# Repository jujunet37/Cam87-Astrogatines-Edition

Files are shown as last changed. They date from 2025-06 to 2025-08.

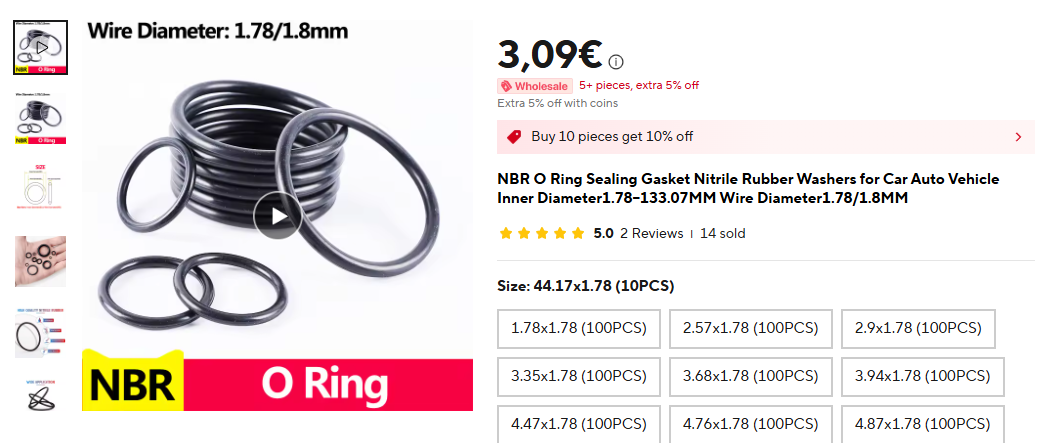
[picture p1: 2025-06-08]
Parts/captures/Capture d'écran 2025-06-08 154612.png

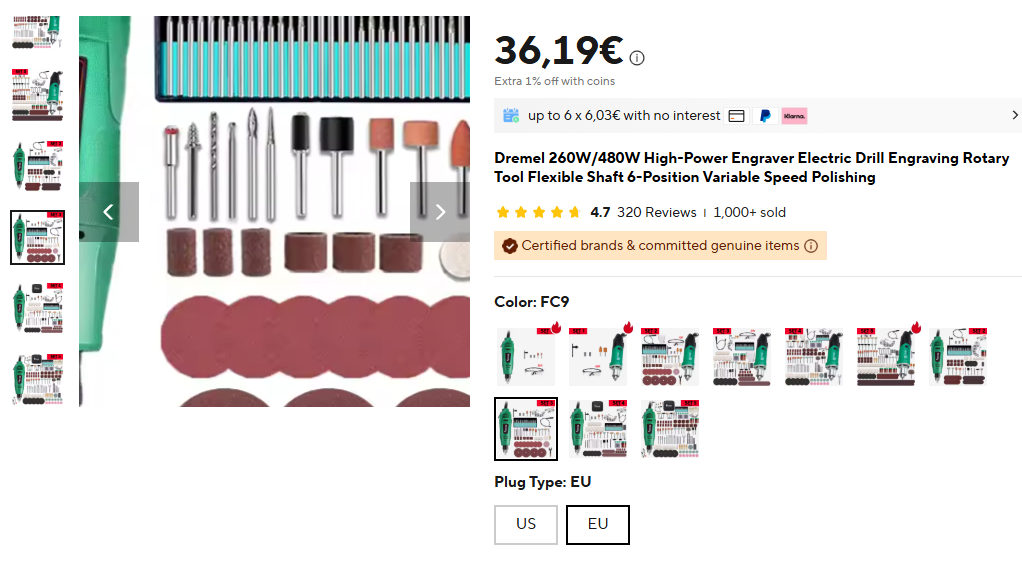
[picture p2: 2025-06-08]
Parts/Other stuff/Capture d'écran 2025-06-08 154455.png

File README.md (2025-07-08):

# Cam87-Astrogatines-Edition

## This repository contains all files needed to build the astronomy Cam87 color camera with a APSC CCD sensor. The resolution of this camera is 6M pixels (3000x2000). Original wiring diagram was made by grim from Astroclub.kiev.ua. Budget for this camera is about 280€ / 320$

## Here are the implementation I made :

- Keep gastight Hammond aluminium enclosure for best low humidity performance and interference shield.
- Power board with all high frequency components are outside the metal box.
- New PCB checked with 4 layers. All logic components on the back side of the sensor side, 3 layers of tracks and a inner full copper plane for best grounding.
- New tiny Mosfet AO4410 that can go up to 18A, tracks are sized for 3.5A max, no more heating mosfet.
- New PID controlled by an ESP32 including a webserver and a new webapp ! Access to sensor and case temperature, box humidity and a temperature graph with your phone or a computer (wifi connexion).
- New design with a aluminium cold finger pressed against the metal box with a 3D printed part. No machining anymore, the .step file is inclued to let it jlccnc do the job !
- Stl files provided for power board holder and enclosure with ESP32 location. Black sensor mask, Cold finger insulator. I provided also a shim to help drilling the lid at the right place.

## Folders :

First folders are numbered for each installation step (Look at the tutorial for each step) : 

- 1 - Drivers FT2232 : Drivers for Windows for the FT2232. I provided 2 drivers, you can check for updates on FTDI website, type FT2232HL and install lastest drivers. WARNING : Since several years FTDI brick non genuine chips. If you purchased your chip on an official reseller, you can update to last driver. If your chip comes from Aliexpress or EBay, be careful about that, if you have any doubt, install the 2.08 provided driver.

- 2 - Flash FT2232 : This is the firmware and the programming utility for flashing the FT2232 chip

- 3a - Viewer : This is the standalone viewer to use with this camera, developped by grim.

- 3b - Flash STM32 : This is the STM32 flash file and the ST-LINK utility for flashing.

- ESP32 PID : In this folder you can found the .ino file for the ESP32 PID and the files to upload on the board for the webserver.

- Gerbers : gerbers files to make the 4 layers PCB (choose 1oz for each layer for cam pcb and 1oz external 0.5oz inner for power board)

- Old ASCOM Platform : This is the ASCOM platform version 6.2 that works with this camera, I  haven't tried newer versions.

- Parts : Here you have the list of components and screen captures to see what parts you need. Also some diagrams.

- STL and STEP Files : This is the stl files for 3D printing and the step file for aluminium CNC machining.

- Wiring diagram : The corrected wiring diagram including the new ESP32 PID and the new cooling diagram.

	- SSID for PID : Cam87 Cooling
	- Password : Value of the speed of the photons that reach your nice camera, in m/s ;-)
	- IP for access : 192.168.4.1

YOUTUBE TUTORIALS !

English : https://www.youtube.com/watch?v=FVaMk6Fg4kI
French : https://www.youtube.com/watch?v=qr7sxIyBGCc

FTDI : https://ftdichip.com/
Astroccd : http://astroccd.org/
Ukrainian Astropolis topic : https://www.astroclub.kiev.ua/forum/index.php?PHPSESSID=su8vh9h1n0l7lrnate4rmb50v5&topic=28929.0

## UPDATE 08/07/2025 :

3D Parts corrected :
- Sensor mask : removed weird cut
- Powerboard Holder : corrected to let the board fit correctly
- Powerboard holder lid : Back corrected for PCB and ESP32 chamber resized.

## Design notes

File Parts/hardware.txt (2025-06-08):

Filtre UV/IR cut 2 inches : SVBONY 2" Filter, UV/IR Cut : 23.98€
Peltier TEC2-19003 30*30*6.0 : 11.09€
Capteur : CCD Sensor for Nikon D70 Image Replacement Repair Part New : 18.32€
ESP32 D1 Mini ESP32 WIFI Bluetooth Development Board CH9102 With ESP-WROOM-32 Module Type-C USB Interface For Arduino : 6.55€

Electronics: €60.85
Hammond Case: €21.17
PCB 1oz/0.5oz Power Supply, 1oz/1oz Logic: €36.25/5 = €7.25

Port Parts:

O-ring 44.17*1.78: €0.60
Silicone Disc 60mmx2mm: €3.18
15mm M48 Bushing: €18.30
M52/M48 Bushing + Cap: €9
M48/M42 Bushing: €3.26

Heat Sink: €18.59
Springs: see details

PU Glue: €6.09
Cold Finger Seals: €1.10
Machined Cold Finger: €46
3D Printing: €14.68
Fan : use again

Screws: €6.54

Details:
M2.5 Nuts: 8: €0.21
M2.5 Flat Head Bolts, 6mm: 2: €0.10
M2.5 Round Head Bolts, 8mm: 2: €0.10
M2.5 Flat Head Bolts, 10mm: 4: €0.16
M2.5 Flat Head Bolts, 16mm: 2: €0.10

M3 Nuts: 10: €0.21
M3 Flat Head Bolts, 6mm: 11: €0.46
M3 Flat Head Bolts, 10mm: 4: €0.20
M3 Washers, 8mm, 0.8mm thick: 8: €0.20
M3 Spacer, 4mm: 11: €1.51
M3 Spacer, 15mm: 4: €0.54

M4 Nuts: 8: €0.48
M4 Flat Head Bolts: 22mm: 4: €0.47
M4 Flat Head Bolts: 40mm: 4: €0.66

Springs: 6mm diameter, 0.6mm wire, 15mm length: 4: €0.54
Springs: 5mm diameter, 0.4mm wire, 5mm length: 4: €0.60

Total: €276

Optional:

M48 TILT Ring: €28.31
M48 Male -> EOS Adapter: €28.39

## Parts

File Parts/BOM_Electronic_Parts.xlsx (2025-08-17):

Resistors
Serigraphy | Size | Value | Number | Reference | Supplier | Shop | Comments
 |  |  |  |  | MULTICOMP PRO | FARNELL
R6S,R11L | R0603 | 100kΩ | 2 | WR06X1003FTL | MULTICOMP PRO | FARNELL
R4S | R0603 | 100Ω | 1 | MCWR06X1000FTL | MULTICOMP PRO | FARNELL
R10L,R14L,R15L,R6L,R11 | R0603 | 10kΩ | 5 | WR06X1002FTLJ | MULTICOMP PRO | FARNELL
R7 | R0603 | 10kΩ | 1 | WR06X1002FTLJ | MULTICOMP PRO | FARNELL
R7L | R0603 | 12kΩ | 1 | WF06P1202FTL | MULTICOMP PRO | FARNELL
R1 | R0603 | 13kΩ | 1 | MCWR06X1302FTL | MULTICOMP PRO | FARNELL
R5 | R0603 | 180Ω | 1 | MCWR06X1800FTL | MULTICOMP PRO | FARNELL
R8L | R0603 | 1kΩ | 1 | WR06X1001FTL | PANASONIC | FARNELL
R7S | R0805 | 1MΩ | 1 | ERJU06F1004V | MULTICOMP PRO | FARNELL
R9L | R0603 | 2.2kΩ | 1 | MR06X2201FTLV | MULTICOMP PRO | FARNELL
R2 | R0603 | 2.4kΩ | 1 | MCWR06X2401FTL | MULTICOMP PRO | FARNELL
R8 | R1206 | 221Ω | 1 | RC1206FR-07221RL | MULTICOMP PRO | FARNELL
R17 | R0603 | 22kΩ | 1 | MCWR06X2202FTL | MULTICOMP PRO | FARNELL
R8S | R0603 | 22Ω | 1 | WR06X22R0FTL | MULTICOMP PRO | FARNELL
R9S | R0603 | 24kΩ | 1 | MCSR06X2402FTL | MULTICOMP PRO | FARNELL
R6 | R0603 | 2kΩ | 1 | MCWR06X2001FTL | VISHAY | FARNELL
R1S,R2S,R10S | R0603 | 3.01Ω | 3 | CRCW06033R01FKEA | MULTICOMP PRO | FARNELL
R9 | R0603 | 4.7kΩ | 1 | MCWR06X4701FTL | BOURNS | FARNELL
R3 | R0805 | 500mΩ | 1 | CRL0805-FW-R470ELF | YAGEO | FARNELL | (0.47 ohm)
R4 | R0805 | 220mΩ | 1 | - | Aliexpress | Aliexpress
R5S | R0603 | 510Ω | 1 | RC0603FR-07510RL | MULTICOMP PRO | FARNELL
R3S | R0603 | 750Ω | 1 | MCWR06X7500FTL |  | FARNELL
R10,R12 | R0603 | 0Ω | 0 | - | - | - | Testing (don't solder)
Capacitors :
C15,C1L,C34L,C22L,C28L,C30L,C31L,C27L,C8,C9L,C12,C12L,C15L,C21L,C26L,C29L,C33L, C1S,C3S | C0603 | 100nF | 19 | CC0603KRX7R9BB104 | YAGEO | FARNELL
C18S | C1206 | 100uF | 1 | GRM31CR60J107MEA8L | MURATA | FARNELL
C8L | CASE-B_3528 | 100uF | 1 | TAJB107K006RNJ | Kyocera AVX | FARNELL
C5S | C0603 | 10pF | 1 | CL10C100JB8NNNC | SAMSUNG ELECTRO-MECHANICS | FARNELL
C17L,C16L,C11L,C13,C16 | C0805 | 10uF | 5 | CL21A106KAYNNNE | SAMSUNG ELECTRO-MECHANICS | FARNELL
C17 | CAP-SMD_L7.3-W4.3-R-RD | 10uF | 1 | TAJD106K025RNJ | AVX | FARNELL
C2,C6,C25L,C36L,C6L,C37L,C7L,C14L,C9,C35L,C2S,C4S,C6S | C0603 | 1uF | 13 | EMK107B7105KA-T | TAIYO YUDEN | FARNELL
C3,C4 | C0603 | 330pF | 2 | GCM1885C1H331JA16D | MURATA | FARNELL
C1,C7,C10,C11 | CAP-SMD_L6.0-W3.2-R-RD | 220uF | 4 | TAJC227K010RNJ | Kyocera AVX | FARNELL | Low ESR
C5 | CAP-SMD_L7.3-W4.3 | 220uF | 1 | TPSE227K016R0050V | Kyocera AVX | FARNELL | Low ESR 0.05ohm vs 0.1 ohm liste LordZurp
C10L | C1206 | 47uF | 1 | CL31A476MPHNNNE | SAMSUNG ELECTRO-MECHANICS | FARNELL
C7S | CASE-D_7343 | 47uF | 1 | TAJD476K025RNJ | Kyocera AVX | FARNELL
C18 | CASE-D_7343 | 47uF | 1 | T491D476K025AT | KEMET | FARNELL
C14 | CAP-SMD_BD6.3-L6.6-W6.6-FD-A | 56uF | 1 | 25SVPF56M | PANASONIC | FARNELL
C23L,C24L | C0603 | 8.2pF | 2 | HH18N8R2B500 | MULTICOMP PRO | FARNELL
Inductors :
L1,L2 | IND-SMD_L12.5-W12.5 | 220uH | 2 | MSS1260T-224KLD | COILCRAFT | FARNELL
L1S | L0805 | 22uH | 1 | LQM21DN220M70L | MURATA | FARNELL
L3 | IND-SMD_L11.5-W10.0_SMMS1040 | 47uH | 1 | 47UH-1040 | - | Aliexpress
Diodes :
VD2S | SOD-123_L2.8-W1.8-LS3.7-RD | LMBR0530T1G | 1 | LMBR0530T1G | - | Aliexpress
D1,VD1,VD2 | SS34_C8678 | SS34_C8678 | 3 | SS34 3A 40V | - | Aliexpress
IC :
U3 | SOIC-16_L9.9-W3.9-P1.27-LS6.0-BL | EL7457CSZ-T13 | 1 | EL7457CSZ | RENESAS | FARNELL
DD5L | LQFP-64_L10.0-W10.0-P0.50-LS12.0-TL | FT2232HL-REEL | 1 | FT2232HL-REEL | FTDI | FARNELL
U2L | TSSOP-8_L4.4-W3.0-P0.65-LS6.4-BL-2 | FT93C46A-UTG-T | 1 | AT93C46DN-SH-B EEPROM | MICROCHIP | FARNELL
VT2S | SOT-23-3_L2.9-W1.3-P1.90-LS2.4-BR | IRLML2803TRPBF | 1 | IRLML2803TRPBF | INFINEON | FARNELL
DD3L | LQFP-48_L7.0-W7.0-P0.50-LS9.0-BL | STM32F103C8T6 | 1 | STM32F103C8T6 | STMICROELECTRONICS | FARNELL
DD1L | SSOP-28 |  | 1 | AD9826KRSZ |  | Aliexpress
Q2 | SOP-8_L4.9-W3.9-P1.27-LS6.0-BL |  | 1 | AO4410 |  | Aliexpress
DD7L | TSSOP-20_L6.5-W4.4-P0.65-LS6.4-BL |  | 1 | CXD1267AN | Sony | Aliexpress
VT1S | SOT-23-3_L2.9-W1.6-P1.90-LS2.8-BR | IRLML6302TRPBF |  | IRLML6302TRPBF | Infineon | Aliexpress
Voltage regulators
U6 | SOT-223_L6.5-W3.5-P2.30-LS7.0-BR | LM1117MPX-50NOPB | 1 | LM1117MPX-50NOPB | ON SEMICONDUCTOR | FARNELL
U1,U2 | SOIC-8_L5.0-W4.0-P1.27-LS6.0-BL | MC34063ADR2G | 2 | MC34063ADR2G | ON SEMICONDUCTOR | FARNELL
U4 | SOT-89-3_L4.5-W2.5-P1.50-LS4.2-BR |  | 1 | 78N06G-AB3-R or best : DI78M06UAB | - | Aliexpress | ebay
U5 | SOT-223-3_L6.5-W3.4-P2.30-LS7.0-BR |  | 1 | AMS1117-3.3 | - | Aliexpress
U4L | SOT-23-3_L2.9-W1.3-P1.83-LS2.4-BR |  | 1 | S-1206B18-M3T1U | - | Aliexpress
Other :
USB1 | USB connector, type B, through hole, elbow | USB-02-B-1B | 1 | USB-02-B-1B | LUMBERG | FARNELL
ZQ1 | CRYSTAL-SMD_4P-L3.2-W2.5-BL | 12MHz | 1 | MCSJK-7U-12.00-12-10-80-B-10 Cristal | MULTICOMP PRO | FARNELL
U9 | SENSOR-TH_HAIGU_DHT22 |  | 1 | DHT22 | - | Aliexpress
ESP32,STPROG | CONN-TH_5P-P1.25_HX-1.25MM-5P-ZZ-MS | 1.25-5P | 2 | MicroJST 1.25-5p | - | Aliexpress | (+ female wire)
TEMP | CONN-TH_3P-P1.25_HX-1.25MM-3P-ZZ-MS | 1.25-3P | 1 | MicroJST 1.25-3p | - | Aliexpress | (+ female wire)
U11 | JST-PH-9-HEADER ANGLE connector | JST 2.0 PH-9p | 1 | JST-PH-9-HEADER ANGLE | - | Aliexpress | (+ female wire)
FAN | CONN-TH_2P-P2.50-XH2.54-2P | XH-2P-2.54 | 1 | XH-2P-2.54 | - | Aliexpress | (+ female wire)
PWR | DC-IN-TH_POWER-JACK 5.5x2.5mm | 5.5x2.5mm | 1 | POWER-JACK | - | Aliexpress
- | Temperature Probe | DS18B20 | 1 | DS18B20 TO-92 | - | Aliexpress
U7 | - | CCD Sensor | 1 | ICX453AQ | Sony | Aliexpress | CCD Sensor for Nikon D70 Image Replacement Repair Part New
U10 | DB9-TH_DB9F_C9900020046 | DB9-Solder, Female | 1 | - | Shop MINGTEXIN | Aliexpress | DB9 Female, straight, 180 degrees, PCB mount
- | DB9-TH_DB9SS | DB9-Solder, Male, gastight | 1 | - | - | Aliexpress | DB9 Connector Male IP68 RS232 485 D-SUB Waterproof Connector 9 Pin Solder Connector D Type Socket Gold Plated Brass 3U
U8 | ESP32 | - | 1 | Mini ESP-WROOM-32 type C CH9102 | - | Aliexpress
- | Peltier TEC2-19003 | - | 1 | - | - | Aliexpress

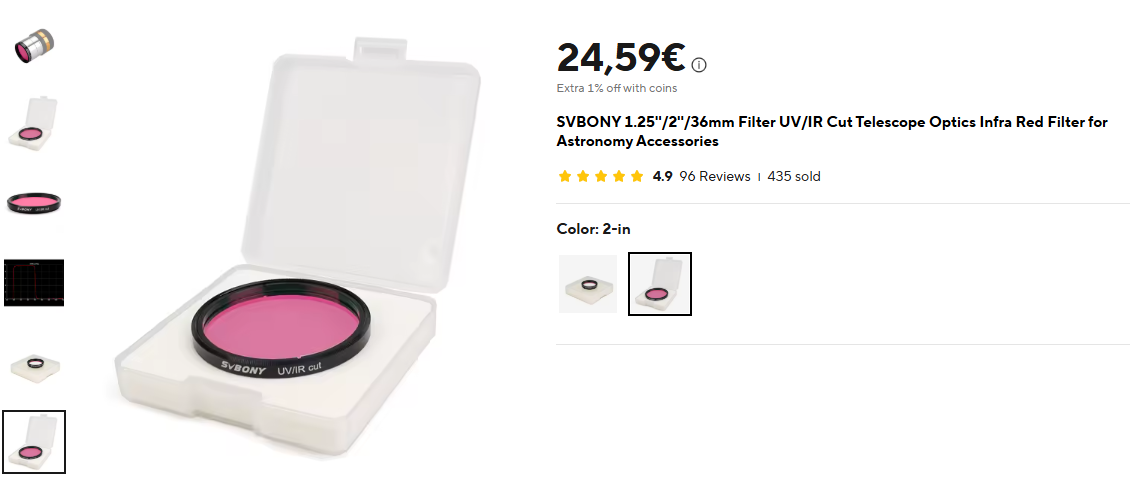
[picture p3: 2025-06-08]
Parts/captures/Capture d'écran 2025-06-08 154024.png

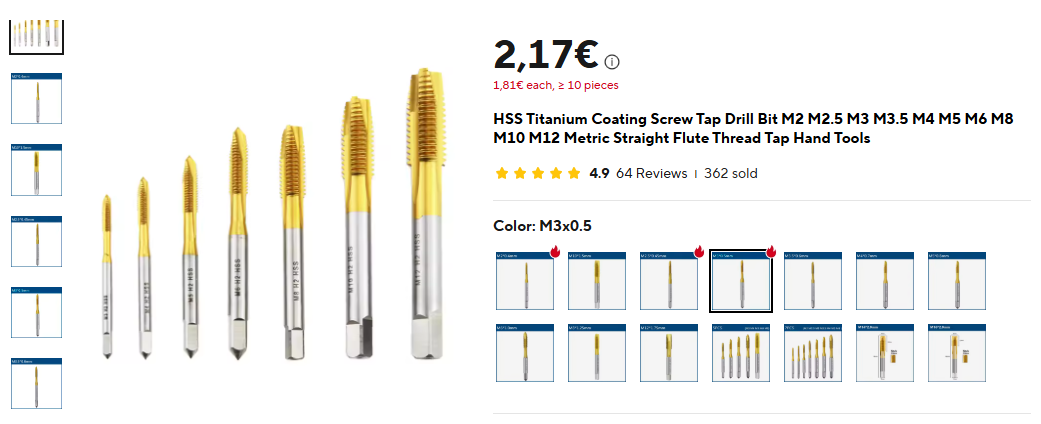
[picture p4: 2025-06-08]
Parts/Other stuff/Capture d'écran 2025-06-08 154422.png

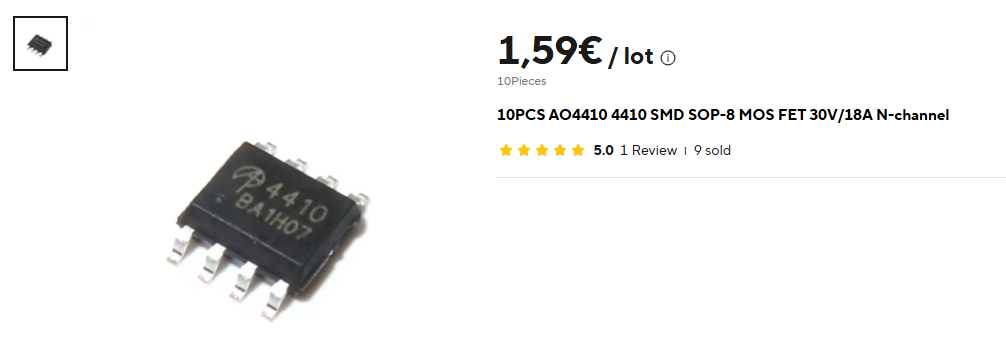
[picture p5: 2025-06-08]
Parts/captures/Capture d'écran 2025-06-08 154749.png

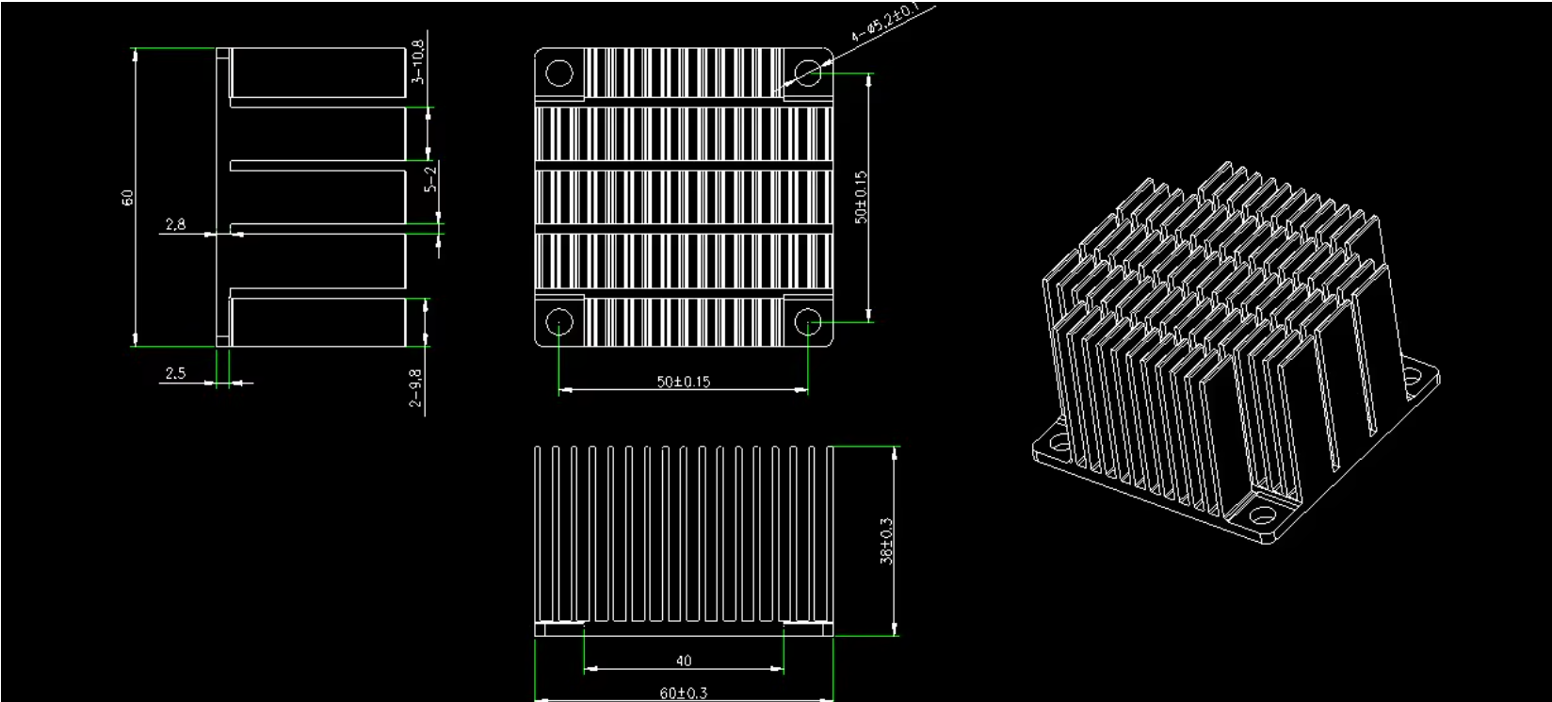
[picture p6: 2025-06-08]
Parts/Heatsink.png

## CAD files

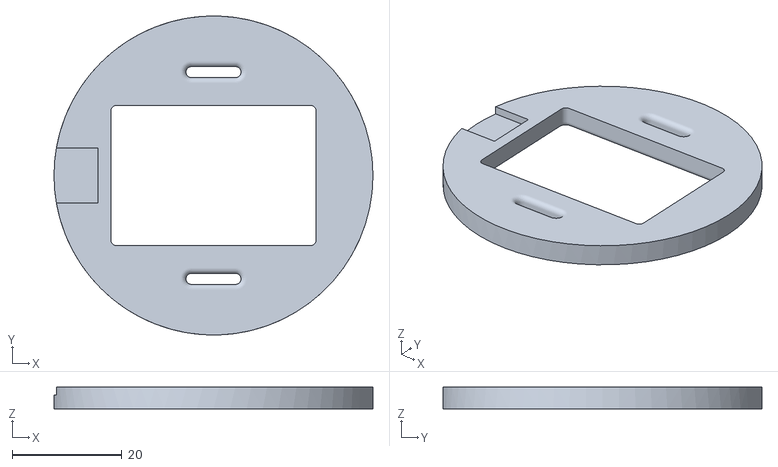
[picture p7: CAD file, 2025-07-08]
STL and STEP Files/SensorMask-Body_V2.stl
58.0 x 58.0 x 4.00

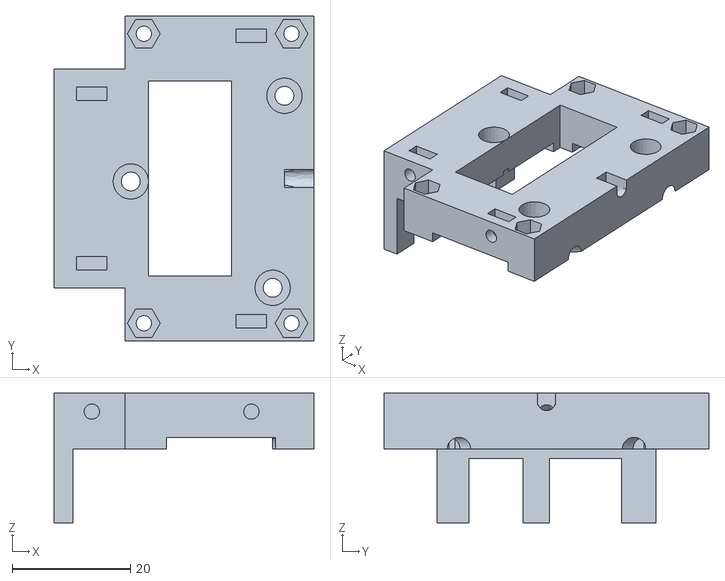
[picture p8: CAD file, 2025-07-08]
STL and STEP Files/PowerBoardHolder_1-Body_V2.stl
44.0 x 55.0 x 22.0

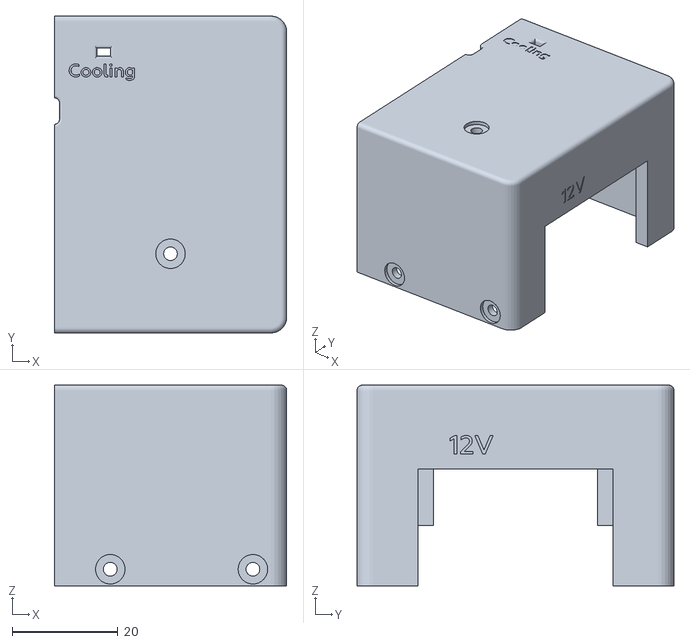
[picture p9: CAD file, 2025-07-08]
STL and STEP Files/PowerBoardHolderLid-Body_V2.stl
44.0 x 60.0 x 38.0

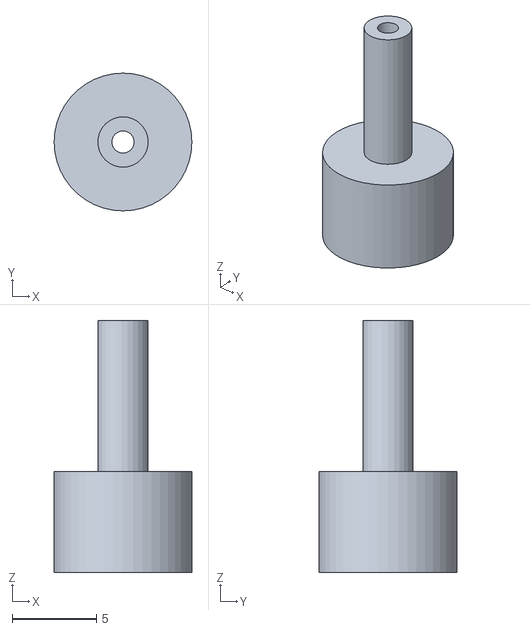
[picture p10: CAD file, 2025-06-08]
STL and STEP Files/DrillGuide2-Body.stl
8.20 x 8.20 x 15.0

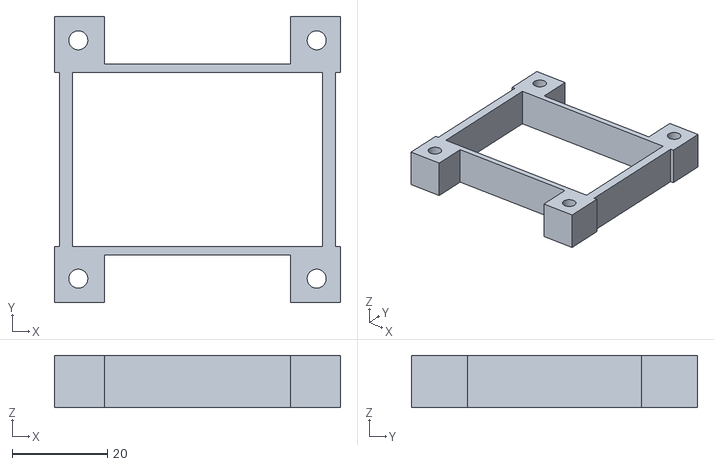
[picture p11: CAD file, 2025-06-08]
STL and STEP Files/FanHolder-Body.stl
60.0 x 60.0 x 11.0

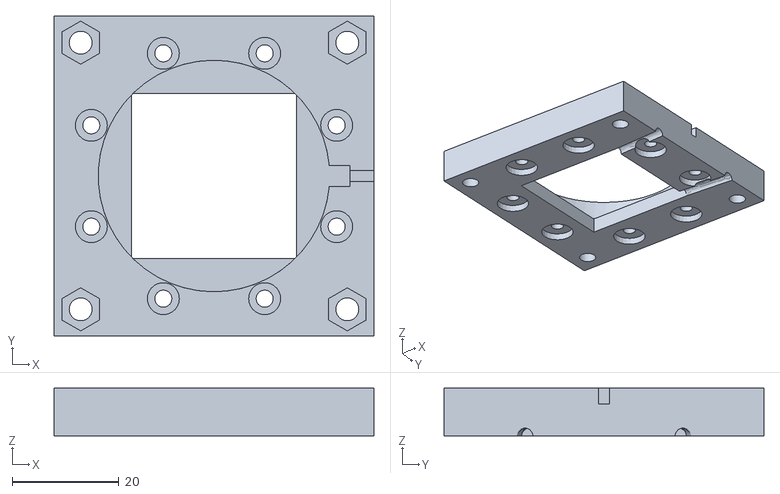
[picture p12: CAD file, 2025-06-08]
STL and STEP Files/ColdfingerHolder-Body.stl
60.0 x 60.0 x 9.00

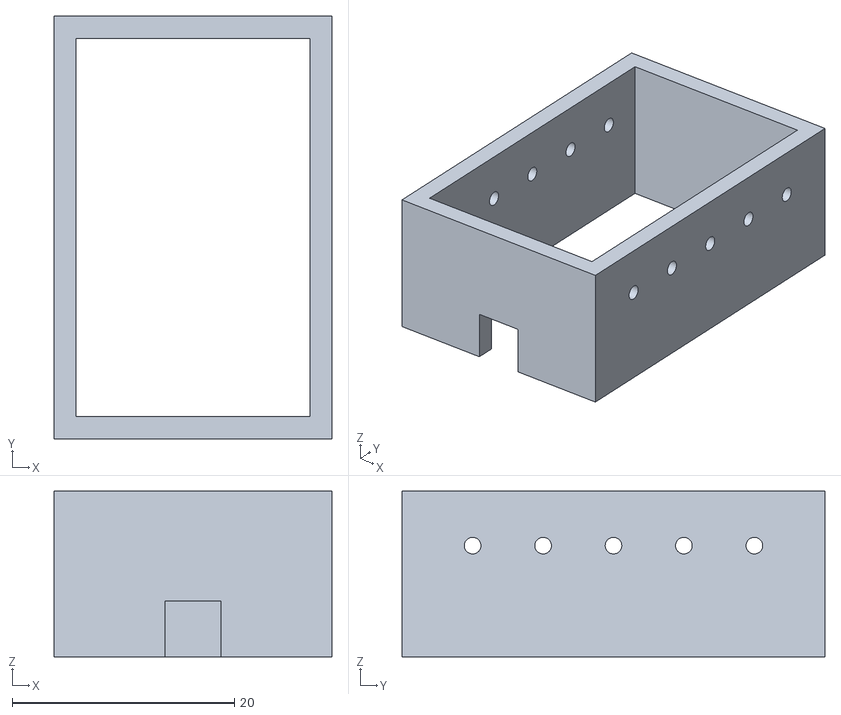
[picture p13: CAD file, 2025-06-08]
STL and STEP Files/ColdFingerInsulator-Body.stl
25.0 x 38.0 x 14.9

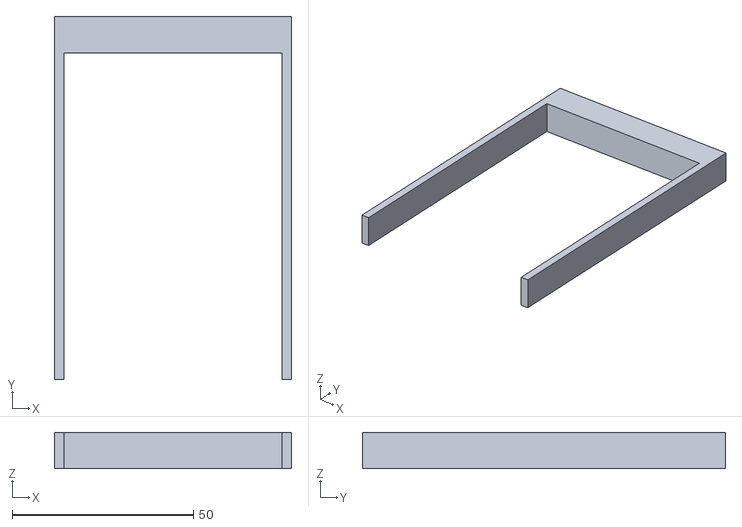
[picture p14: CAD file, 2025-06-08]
STL and STEP Files/Cale-Body.stl
65.4 x 100.1 x 10.0

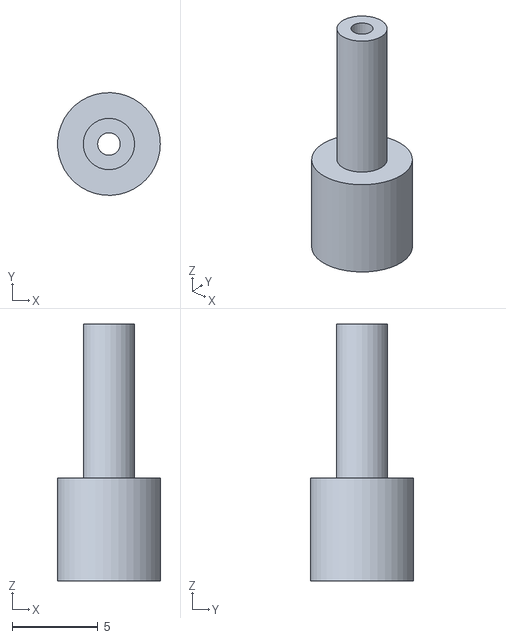
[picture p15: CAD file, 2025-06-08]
STL and STEP Files/DrillGuide-Body.stl
5.99 x 6.00 x 15.0

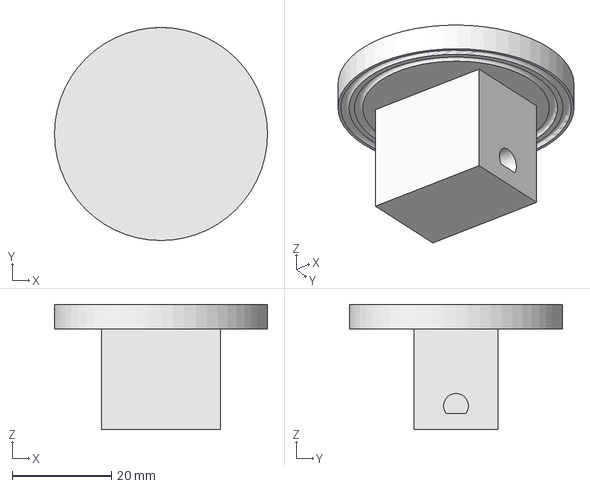
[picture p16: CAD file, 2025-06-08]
STL and STEP Files/ColdFinger-Body.step
43.0 x 43.0 x 25.3 mm

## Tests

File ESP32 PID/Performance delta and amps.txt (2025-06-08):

Tests @ 23°C

TES1-12701

1.18A. (fan : 240mA) -> 0.94A

-0.5°C Delta = 23°C (Cam OFF) Box Temp : 20°C
4.0°C Delta = 19°C (Cam ON) Box Temp : 30°C

TEC2-19003

2.24A. (fan : 240mA) -> 2.00A

-5.5°C Delta = 29°C (Cam OFF) Box Temp : 18°C
-1°C Delta = 24°C (Cam ON) Box Temp : 30°C

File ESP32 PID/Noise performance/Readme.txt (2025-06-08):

I made some measures to check thermal noise and read noise with effects of cooling.

- Noise is for several seconds exposure (thermal noise) 
- Read noise is 0.001s exposure

Checked also the effect of gain settings

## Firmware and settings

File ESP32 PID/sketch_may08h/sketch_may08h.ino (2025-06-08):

//This is the main PID code for the Cam87 Astrogatines Edition.

#ifdef ESP32
  #include <WiFi.h>
  #include <ESPAsyncWebServer.h>
#else
  // Arduino.h, ESP8266WiFi.h, etc. commented out as per original
#endif
#include <OneWire.h>
#include <DallasTemperature.h>
#include <AsyncTCP.h>
#include <Adafruit_Sensor.h>
#include "DHT.h"
#include "LittleFS.h"
#include <Arduino_JSON.h>
#include <PID_v1.h>

// PID Configuration
double Setpoint, Input, Outp;
double Kp = 200, Ki = 10, Kd = 5;
PID myPID(&Input, &Outp, &Setpoint, Kp, Ki, Kd, DIRECT);
int WindowSize = 5000;
unsigned long windowStartTime;

// PID Adaptive Configuration
float ambientTemp = 0.0; // Stores initial ambient temperature
bool ambientRecorded = false;
const float maxCoolingDelta = 20.0; // Maximum cooling capability (20°C below ambient)

// Event and JSON variables
AsyncEventSource events("/events");
JSONVar readings;

// Sensor pins and instances
#define ONE_WIRE_BUS 4
#define DHTPIN 0
#define DHTTYPE DHT22    

OneWire oneWire(ONE_WIRE_BUS);
DallasTemperature sensors(&oneWire);
DHT dht(DHTPIN, DHTTYPE);

// Temperature variables
char temperatureC[10] = "";
float dht_h;
float dht_t;
float tempC;
char dewPointStr[10] = "0.0"; // Stores last calculated Dew Point

// Timer variables
unsigned long lastTime = 0;  
unsigned long lastDewPCalc = 0;
unsigned long timerDelay = 10000;
const unsigned long dewPCalcInterval = 30000; // 30 seconds for DewP
const int output = 2;

// Threshold and control variables
char inputMessage[10] = "25.0";
char enableArmChecked[10] = "checked";
char inputMessage2[10] = "false";
char coolingstate[10] = "OFF";

// Network credentials
const char* ssid = "Cam87 Cooling";
const char* password = "299792458";

// Parameter names
const char* PARAM_INPUT_1 = "threshold_input";
const char* PARAM_INPUT_2 = "enable_arm_input";

// Web server
AsyncWebServer server(80);

// Helper function to convert float to char array
void floatToChar(float value, char* output, int precision = 1) {
  dtostrf(value, 0, precision, output);
}

void updatePIDParameters() {
  if (ambientRecorded) {
    float delta = ambientTemp - Setpoint;
    
    // Constrain delta to system capabilities
    delta = constrain(delta, 0, maxCoolingDelta);
    
    // Adaptive PID tuning rules
    if (delta > 15.0) {
      // Large delta - aggressive tuning
      Kp = 300;
      Ki = 15;
      Kd = 10;
    } 
    else if (delta > 5.0) {
      // Medium delta - moderate tuning
      Kp = 200;
      Ki = 10;
      Kd = 5;
    }
    else {
      // Small delta - conservative tuning
      Kp = 100;
      Ki = 5;
      Kd = 2;
    }
    
    // Apply new parameters
    myPID.SetTunings(Kp, Ki, Kd);
    
    Serial.print("Delta: ");
    Serial.print(delta);
    Serial.print("°C - New PID values: Kp=");
    Serial.print(Kp);
    Serial.print(", Ki=");
    Serial.print(Ki);
    Serial.print(", Kd=");
    Serial.println(Kd);
  }
}

// Sensor reading functions
void getSensorReadings(char* jsonOutput, size_t size) {
  sensors.requestTemperatures();
  float temp = sensors.getTempCByIndex(0); // Reads the first sensor found
  char tempStr[10];
  floatToChar(temp, tempStr);
  
  snprintf(jsonOutput, size, "{\"temperature\":\"%s\"}", tempStr); 
}

void initLittleFS() {
  if (!LittleFS.begin()) {
    Serial.println("An error has occurred while mounting LittleFS");
  }
  else {
    Serial.println("LittleFS mounted successfully");
  }
}

void readDHTTemperature(char* output, size_t size) {
  float readt = dht.readTemperature();
  if (isnan(readt)) {    
    Serial.println("Failed to read from DHT sensor!");
    strncpy(output, "0.0", size);
    dht_t = 0.0;
  }
  else {
    if (readt > 0) { dht_t = readt; }
    floatToChar(dht_t, output);
  }
}

void readDHTHumidity(char* output, size_t size) {
  float readh = dht.readHumidity();
  if (isnan(readh)) {
    Serial.println("Failed to read from DHT sensor!");
    strncpy(output, "0.0", size);
    dht_h = 0.1;
  }
  else {
    dht_h = readh;
    floatToChar(dht_h, output);
  }
}

void calculateDewPoint() {
  if (millis() - lastDewPCalc >= dewPCalcInterval) {
    // Use 0.1% when MEASURED humidity is 0.0%
    float calc_h = (fabs(dht_h) < 0.0001f) ? 0.1f : dht_h;
    
    // Magnus formula for dew point
    float DewP = (237.7f*(logf(calc_h/100.0f)+(17.27f*dht_t)/(237.7f+dht_t)))/
                 (17.27f-(logf((calc_h/100.0f))+(17.27f*dht_t)/(237.7f+dht_t)));
    
    if (isnan(DewP)) {
      strncpy(dewPointStr, "0.0", sizeof(dewPointStr));
      Serial.println("DewP calculation error!");
    } else {
      floatToChar(DewP, dewPointStr, 1);
      Serial.print("Calculated DewP: ");
      Serial.println(DewP);
    }
    lastDewPCalc = millis();
  }
}

void readDSTemperatureC(char* output, size_t size) {
  sensors.requestTemperatures(); 
  tempC = sensors.getTempCByIndex(0);

  if(tempC == -127.00) {
    Serial.println("Failed to read from DS18B20 sensor");
    strncpy(output, "--", size);
  } 
  else {
    floatToChar(tempC, output);
  }
}

const char index_html[] PROGMEM = R"rawliteral(
<!DOCTYPE HTML><html>
</html>)rawliteral";

void processor(const String& var, char* output, size_t size){
  if(var == "TEMPERATUREC"){
    strncpy(output, temperatureC, size);
  }
  else if(var == "TEMPERATURE"){
    char temp[10];
    readDHTTemperature(temp, sizeof(temp));
    strncpy(output, temp, size);
  }
  else if(var == "HUMIDITY"){
    char hum[10];
    readDHTHumidity(hum, sizeof(hum));
    strncpy(output, hum, size);
  }
  else if(var == "DewP"){
    strncpy(output, dewPointStr, size);
  }
  else if(var == "inputMessage"){
    strncpy(output, inputMessage, size);
  }
  else if(var == "inputMessage2"){
    strncpy(output, coolingstate, size);
  }
  else {
    strncpy(output, "", size);
  }
}

void setup(){
  Serial.begin(115200);
  Serial.println();
  
  sensors.begin();
  dht.begin();
  
  // Record ambient temperature at startup
  float initialTemp = dht.readTemperature();
  if (!isnan(initialTemp)) {
    ambientTemp = initialTemp;
    ambientRecorded = true;
    Serial.print("Recorded ambient temperature: ");
    Serial.println(ambientTemp);
  }

  WiFi.softAP(ssid, password);
  IPAddress IP = WiFi.softAPIP();
  Serial.print("AP IP address: ");
  Serial.println(IP);
  
  initLittleFS();

  windowStartTime = millis();
  Setpoint = atof(inputMessage);
  updatePIDParameters();
  myPID.SetOutputLimits(0, WindowSize);
  myPID.SetMode(AUTOMATIC);

  readDSTemperatureC(temperatureC, sizeof(temperatureC));
  Serial.println();
  Serial.println(WiFi.localIP());

  pinMode(output, OUTPUT);
  digitalWrite(output, LOW);

  // Initial Dew Point calculation
  calculateDewPoint();

  // Web server routes
  server.on("/", HTTP_GET, [](AsyncWebServerRequest *request){
    request->send(LittleFS, "/index.html", "text/html");
  });

  server.on("/get", HTTP_GET, [](AsyncWebServerRequest *request) {
    if (request->hasParam(PARAM_INPUT_1)) {
      strncpy(inputMessage, request->getParam(PARAM_INPUT_1)->value().c_str(), sizeof(inputMessage));
      Setpoint = atof(inputMessage);
      updatePIDParameters();
      
      if (request->hasParam(PARAM_INPUT_2)) {
        strncpy(inputMessage2, request->getParam(PARAM_INPUT_2)->value().c_str(), sizeof(inputMessage2));
        strncpy(enableArmChecked, "checked", sizeof(enableArmChecked));
      }
      else {
        strncpy(inputMessage2, "false", sizeof(inputMessage2));
        strncpy(enableArmChecked, "", sizeof(enableArmChecked));
      }
    }

    if (strcmp(inputMessage2, "true") == 0) { 
      strncpy(coolingstate, "ON", sizeof(coolingstate));
    } 
    else { 
      strncpy(coolingstate, "OFF", sizeof(coolingstate));
    }
   
    Serial.println(inputMessage);
    Serial.println(inputMessage2);
    Serial.println(coolingstate);
    request->send(204, "text/html", "");
  });
  
  server.serveStatic("/", LittleFS, "/");
  
  server.on("/readings", HTTP_GET, [](AsyncWebServerRequest *request){
    char json[100];
    getSensorReadings(json, sizeof(json));
    request->send(200, "application/json", json);
  });
  
  events.onConnect([](AsyncEventSourceClient *client){
    if(client->lastId()){
      Serial.printf("Client reconnected! Last message ID that it got is: %u\n", client->lastId());
    }
    client->send("hello!", NULL, millis(), 10000);
  });
  server.addHandler(&events);

  server.on("/temperaturec", HTTP_GET, [](AsyncWebServerRequest *request){
    request->send_P(200, "text/plain", temperatureC);
  });
  
  server.on("/temperature", HTTP_GET, [](AsyncWebServerRequest *request){
    char temp[10];
    readDHTTemperature(temp, sizeof(temp));
    request->send_P(200, "text/plain", temp);
  });
  
  server.on("/humidity", HTTP_GET, [](AsyncWebServerRequest *request){
    char hum[10];
    readDHTHumidity(hum, sizeof(hum));
    request->send_P(200, "text/plain", hum);
  });

  server.on("/DewP", HTTP_GET, [](AsyncWebServerRequest *request){
    request->send_P(200, "text/plain", dewPointStr);
  });

  server.on("/inputMessage", HTTP_GET, [](AsyncWebServerRequest *request){
    request->send_P(200, "text/plain", inputMessage);
  });  
  
  server.on("/coolingstate", HTTP_GET, [](AsyncWebServerRequest *request){
    request->send_P(200, "text/plain", coolingstate);
  });  

  server.begin();
}
 
void loop(){
  Input = tempC;
  
  // Update PID parameters if setpoint changes
  static float lastSetpoint = Setpoint;
  if (Setpoint != lastSetpoint) {
    updatePIDParameters();
    lastSetpoint = Setpoint;
  }
  
  myPID.Compute();
  
  if (millis() - windowStartTime > WindowSize) {
    windowStartTime += WindowSize;
  }
  
  if ((Outp < millis() - windowStartTime) && (strcmp(inputMessage2, "true") == 0)) {
    digitalWrite(output, HIGH);
  }
  else {
    digitalWrite(output, LOW);
  }

  // Calculate Dew Point every 30 seconds
  calculateDewPoint();

  if ((millis() - lastTime) > timerDelay) {
    readDSTemperatureC(temperatureC, sizeof(temperatureC));
    events.send("ping", NULL, millis());
    
    char json[100];
    getSensorReadings(json, sizeof(json));
    events.send(json, "new_readings", millis());
    
    lastTime = millis();
  }  
}

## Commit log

2025-06-08 Cam87 files
    [BOM_Electronic_Parts.xlsx, Cale-Body.stl, ColdFinger-Body.step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]
2025-06-13 msie à jour
    [BOM_Electronic_Parts.xlsx]
2025-06-23 update drivers
2025-07-08 update 3D parts
    update 3D parts
    [PowerBoardHolderLid-Body.stl, PowerBoardHolderLid-Body_V2.stl, PowerBoardHolder_1-Body.stl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]
2025-08-07 ajout Pick and place
    [PickAndPlace_PCB_Cam87_Routage-part-1-Alim_2025-08-07.csv, PickAndPlace_PCB_Cam87_Routage-part-2-Cam-Board-V2_2025-08-07.csv]
2025-08-17 mise à jour BOM
    [BOM_Electronic_Parts.xlsx, PickAndPlace_PCB_Cam87_Routage-part-1-Alim_2025-08-07.csv, PickAndPlace_PCB_Cam87_Routage-part-1-Alim_2025-08-17.csv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]
